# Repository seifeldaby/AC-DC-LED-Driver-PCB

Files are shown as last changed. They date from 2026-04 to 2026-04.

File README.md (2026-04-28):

# ⚡ AC-to-DC LED Driver PCB — Five-Channel Infrared LED Driver NOTE : photos under review

<p align="center">
  Final Board Powered On
</p>

<p align="center">
  
  
  
  
</p>

---

## 📋 Project Overview

This project is a **fully hand-fabricated AC-to-DC regulated power supply** designed to drive **five infrared LEDs** simultaneously. It was developed as part of the Electrical & Electronics Engineering curriculum at **Assiut University**, under the supervision of **Dr. Khalil Ismail**.

The circuit converts a **17 V peak / 50 Hz sinusoidal AC** input into a stable **9.1 V regulated DC output** using a Zener shunt regulator, and distributes ~18.8 mA to each of the five IR LED branches.

---

## 🧩 Circuit Architecture

The circuit is structured as a cascade of four functional stages:

```
AC Input → Full-Wave Bridge Rectifier → Capacitive Filter → Zener Regulator → 5× LED Branches
```

| Stage | Component | Value / Part |
|---|---|---|
| AC Input | Terminal Block (TB1) | 2-Pin, 5.08 mm pitch |
| Rectifier | D1–D4 | 1N4007 (×4) |
| Filter | C1 | 2200 µF / 50 V Electrolytic |
| Pre-reg Resistor | R1 | 47 Ω, ≥ 1 W |
| Zener Regulator | D5 | 1N4739A (9.1 V, 1 W) |
| LED Resistors | R2–R6 | 420 Ω, ¼ W (×5) |
| LEDs | LED1–LED5 | Infrared LEDs (Vf ≈ 1.2 V) |

---

## 📐 Key Design Calculations

| Parameter | Value |
|---|---|
| AC Peak Voltage | 17 V |
| AC RMS Voltage | 12.02 V |
| Peak Voltage After Rectifier | 15.6 V |
| Ripple Voltage (p-p) | ~0.2 V |
| Regulated Output (Zener) | 9.1 V |
| Current Through R1 | ~134 mA |
| Zener Current (max) | ~90 mA |
| Zener Power Dissipation (max) | ~0.82 W |
| Current Per LED Branch | ~18.8 mA |
| Total LED Current | ~94 mA |

---

## 🖥️ Step 1 — Schematic Design in LTspice

The circuit was first drawn and simulated in **LTspice** using a `.tran 0.5` transient analysis (500 ms window) to verify rectification, filtering, and regulation behaviour before committing to PCB layout.

<p align="center">
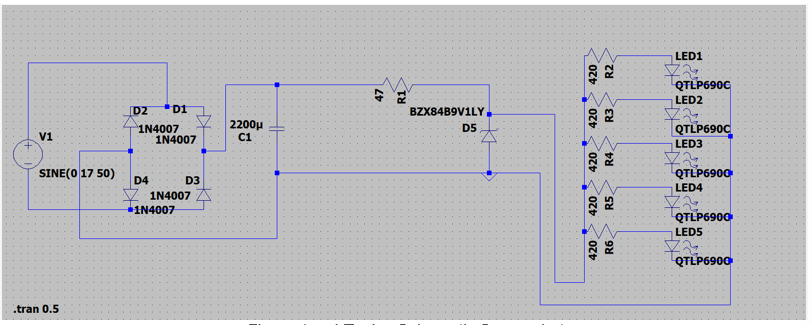
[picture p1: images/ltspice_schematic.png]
LTspice Schematic
  
  <br><em>Figure 1 — LTspice Schematic</em>
</p>

### Simulation Waveforms

**Rectified & Filtered DC Voltage (V_cap):**

<p align="center">
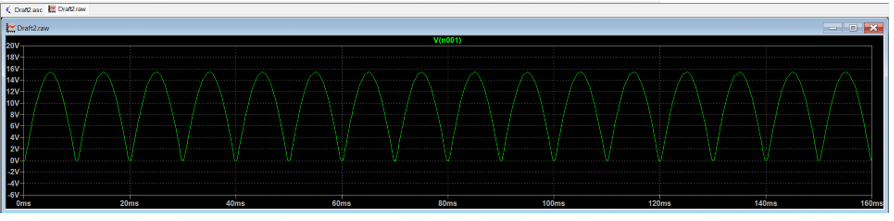
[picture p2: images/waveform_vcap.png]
Rectified and Filtered DC
  
  <br><em>Figure 2 — V_cap: Pulsating DC before regulation (~15.4 V with 0.2 V ripple)</em>
</p>

**Regulated Zener Output (9.1 V):**

<p align="center">
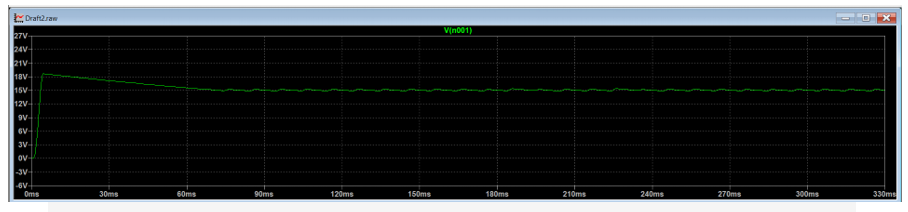
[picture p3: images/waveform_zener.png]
Zener Regulated Output
  
  <br><em>Figure 3 — Stable 9.1 V regulated output</em>
</p>

---

## 🖨️ Step 2 — PCB Design in KiCad

After successful simulation, the schematic was transferred to **KiCad** for PCB layout. Key design decisions included:

- AC input traces routed with **≥ 2 mm creepage/clearance** from DC traces (per IEC 60950)
- Zener diode and R1 placed close together to **minimise high-current trace length**
- LED resistors (R2–R6) arranged in a **symmetrical column** matching LED positions
- Terminal block mounted at **board edge** for direct cable access
- All components on the **top layer**; solder joints on the **bottom layer**

<p align="center">
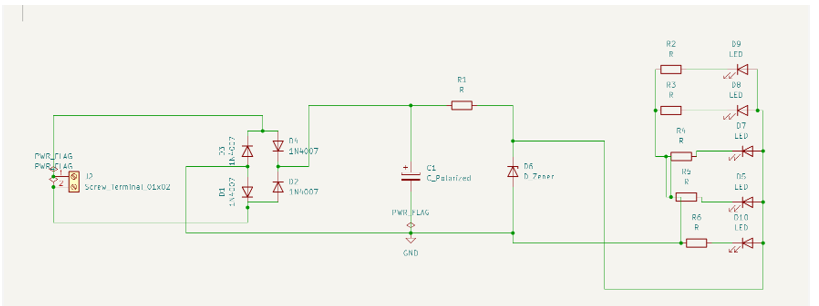
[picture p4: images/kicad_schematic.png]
KiCad Schematic
  
  <br><em>Figure 5 — Schematic captured in KiCad</em>
</p>

<p align="center">
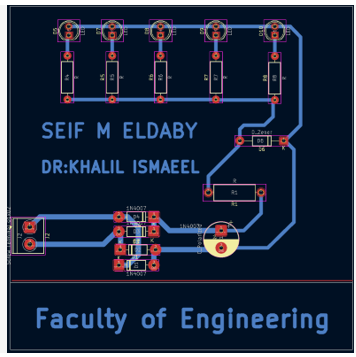
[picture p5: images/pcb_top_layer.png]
PCB Top Layer
  
  <br><em>Figure 6 — PCB Top Layer Layout</em>
</p>

<p align="center">
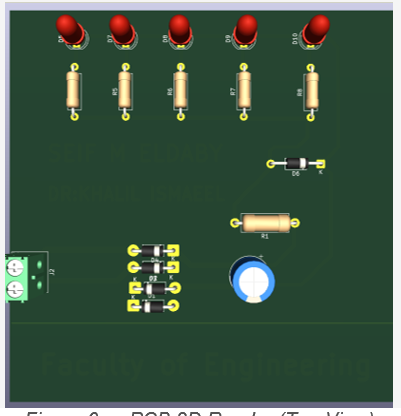
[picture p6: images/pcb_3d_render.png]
PCB 3D Render
  
  <br><em>Figure 7 — PCB 3D Render (Top View)</em>
</p>

---

## 🏭 Step 3 — PCB Manual Fabrication

The board was fabricated entirely by hand using the **toner transfer method**. Below is the complete process:

### 3.1 Toner Transfer

The layout was printed on **glossy paper** using a laser printer, then heat-transferred onto the copper-clad board using an iron.

<p align="center">
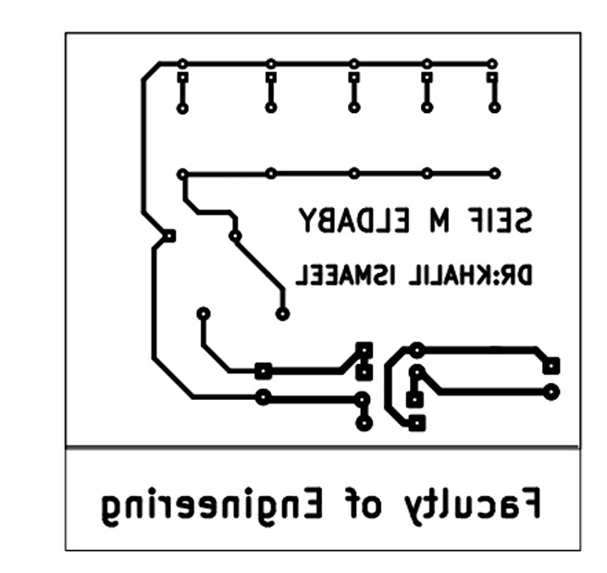
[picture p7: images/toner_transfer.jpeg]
Toner Transfer
  
  <br><em>Figure 8 — Toner transferred onto copper-clad board</em>
</p>

### 3.2 Chemical Etching

The board was submerged in **Ferric Chloride (FeCl₃)** solution to dissolve the exposed copper, leaving only the toner-protected traces.

<p align="center">
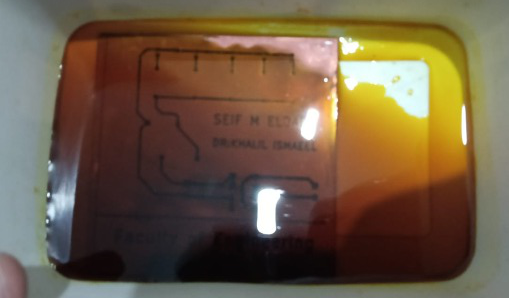
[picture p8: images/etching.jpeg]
Chemical Etching
  
  <br><em>Figure 9 — Board during chemical etching process</em>
</p>
<p align="center">
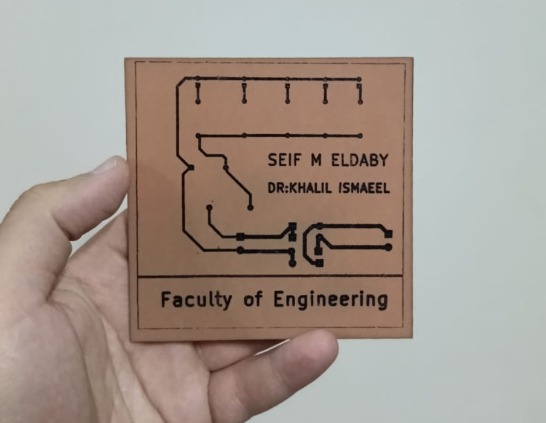
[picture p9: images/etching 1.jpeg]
Chemical Etching
  
</p>
### 3.3 Cleaning & Inspection

Toner was removed with **Acetone/Thinner** to reveal the copper tracks. A visual inspection was performed to check for shorts or broken traces.

<p align="center">
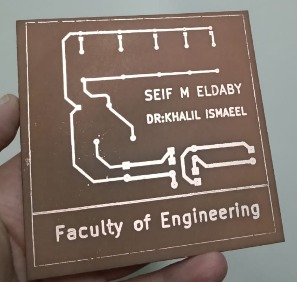
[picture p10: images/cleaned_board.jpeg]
Cleaned Board
  
  <br><em>Figure 10 — Board after cleaning, copper traces visible</em>
</p>

### 3.4 Continuity Testing

A **Digital Multimeter** was used to verify electrical integrity of all traces before drilling.

<p align="center">
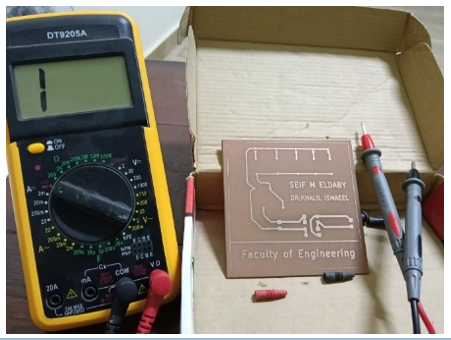
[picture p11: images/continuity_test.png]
Continuity Testing
  
  <br><em>Figure 11 — Continuity testing with DMM</em>
</p>

### 3.5 Drilling

Precision holes were drilled using a **mini drill press** with bit sizes of **0.8 mm – 1.0 mm** depending on component lead diameter.

<p align="center">
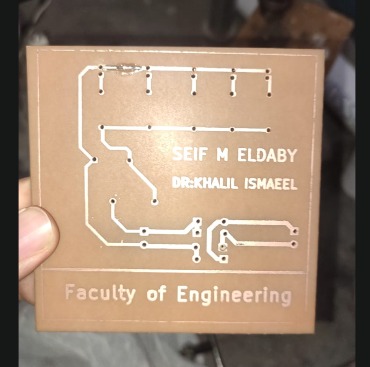
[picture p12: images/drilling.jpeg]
Drilling
  
  <br><em>Figure 12 — Drilling through-hole component pads</em>
</p>

### 3.6 Component Assembly & Soldering

Components were placed per the silkscreen layout and soldered using a **temperature-controlled iron** with lead-tin wire, targeting concave solder joints for maximum reliability.
</p>
<p align="center">
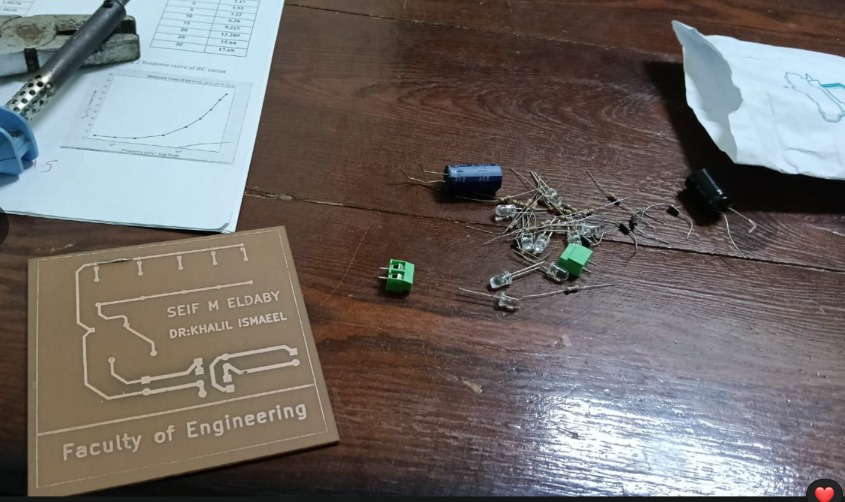
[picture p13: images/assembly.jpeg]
  
  <br><em>Figure 13 — Components being assempled onto the board</em>
</p>
<p align="center">
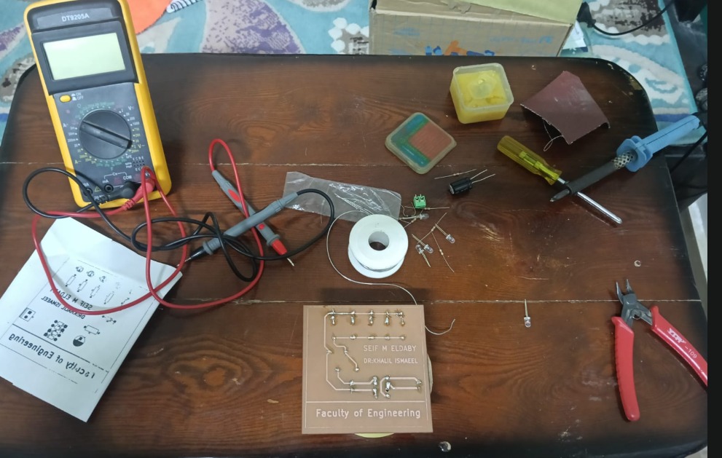
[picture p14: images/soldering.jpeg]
Soldering
  
  <br><em>Figure 13 — Components being soldered onto the board</em>
</p>
<p align="center">
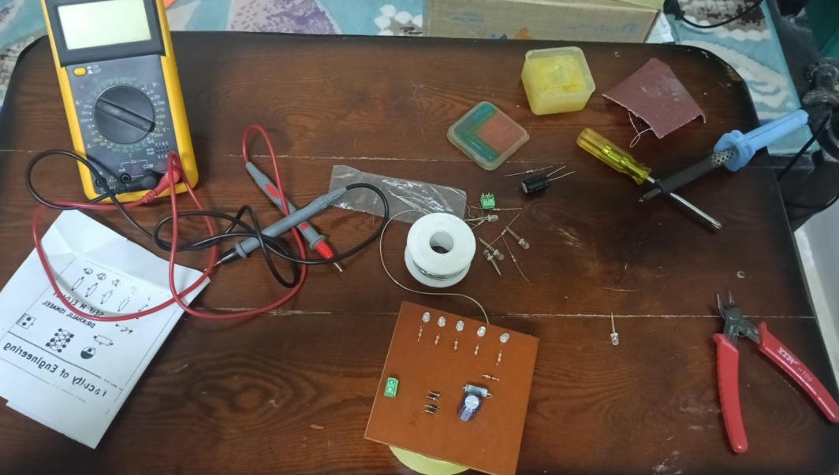
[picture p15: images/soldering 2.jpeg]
Soldering
  
  <br><em>Figure 13 — Components being soldered onto the board</em>

---

## ✅ Step 4 — Testing & Verification

After assembly, the circuit was powered through a **safety isolation transformer** for the initial power-up. Output voltage and LED branch currents were measured with a multimeter to confirm they met specifications.

<p align="center">
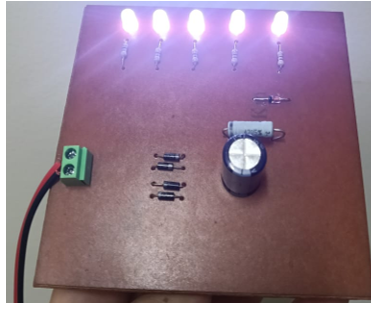
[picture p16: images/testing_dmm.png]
Testing with DMM
  
  <br><em>Figure 14 — Measuring output voltage and current </em>
</p>

---

## 🎉 Final Result

The completed board with all five IR LEDs operational:

<p align="center">
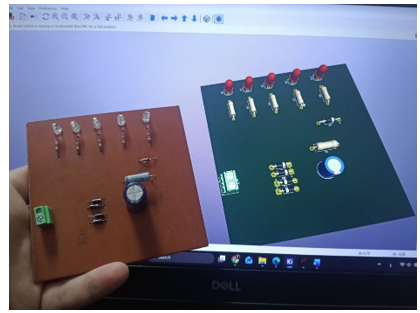
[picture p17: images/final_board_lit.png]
Final Board Powered
  
  <br><em>Figure 15 — Final assembled board with LEDs powered on</em>
</p>

The board was then cleaned with **Isopropyl Alcohol (IPA)** to remove flux residues.

---

## 🔬 Results Summary

| Measurement | Expected | Result |
|---|---|---|
| Regulated Output Voltage | 9.1 V | ✅ 9.1 V |
| LED Branch Current | ~18.8 mA | ✅ Within spec |
| Ripple Voltage | ~0.2 V p-p | ✅ Well-smoothed |
| Zener Power Dissipation | ≤ 1 W | ✅ ~0.82 W max |
| All LEDs Operational | 5/5 | ✅ 5/5 |

---

## 🛠️ Tools Used

| Tool | Purpose |
|---|---|
| **LTspice** | Circuit simulation & waveform analysis |
| **KiCad** | Schematic capture & PCB layout |
| **Ferric Chloride** | Chemical etching |
| **Soldering Iron** | Component assembly |
| **Digital Multimeter** | Continuity testing & measurements |

---

## 📁 Repository Structure

```
📦 AC-DC-LED-Driver-PCB
 ┣ 📂 images/                  ← All photos and screenshots
 ┣ 📂 ltspice/                 ← LTspice simulation files 
 ┣ 📂 kicad/                   ← KiCad project files 
 ┣ 📄 README.md                ← This file
 ┗ 📄 LED_Driver_PCB_Report.pdf ← Full technical report
```

---

## 👤 Author

**Seif Elden Mostafa Salah Eldaby**  
Electrical & Electronics Engineering — Assiut University (Class of 2029)  

**Supervisor:** Dr. Khalil Ismail  
Faculty of Engineering — Assiut University

---

## 📄 License

This project is submitted as academic work at Assiut University. Feel free to use it for learning purposes with proper attribution.

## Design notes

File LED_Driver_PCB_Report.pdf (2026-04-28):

AC-to-DC LED Driver Circuit — Technical Report

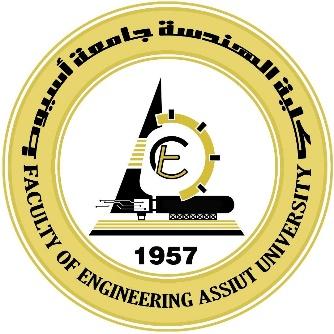
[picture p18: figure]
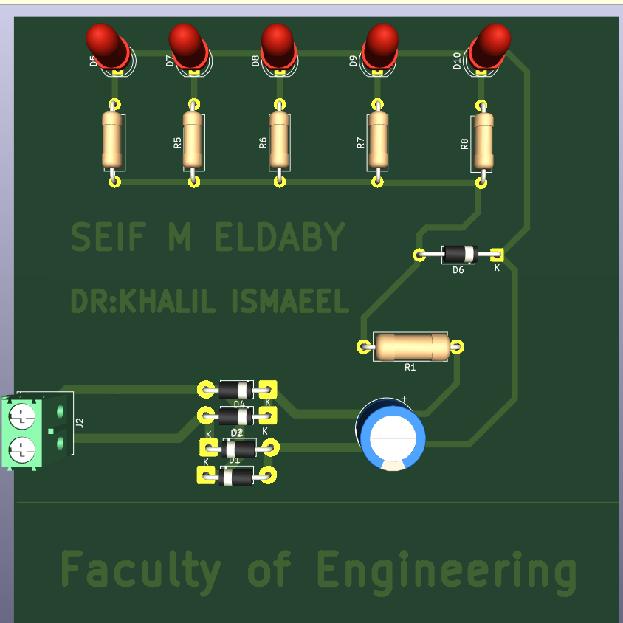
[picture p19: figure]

Assiut University — EEE Department | Page 1

## ASSIUT UNIVERSITY

Faculty of Engineering — Electrical & Electronics Engineering Department

### TECHNICAL REPORT

## AC-to-DC Power Supply with Zener Regulation

### for a Five-Channel Infrared LED Driver

## Prepared by :Seif Elden Mostafa Salah

# Supervisor: Dr. Khalil Ismail

## 1. Introduction

This report documents the design, analysis, and PCB implementation of an AC-to-DC regulated power supply circuit intended to drive five infrared LEDs . The circuit converts a 50 Hz sinusoidal AC input into a stable regulated DC voltage using a full-wave bridge rectifier, a bulk filter capacitor, a dropping resistor, and a 9.1 V Zener diode regulator. The regulated output is distributed to five identical LED branches, each protected by a dedicated current-limiting resistor.
The project was simulated in LTspice and then implemented as a printed circuit board (PCB). The actual hardware substitutes the schematic's terminal connections with a dedicated 2-pin terminal block (5.08 mm pitch) and uses a 1N4739A (9.1 V, 1 W) Zener diode in place of the BZX84B9V1LY used in simulation.

## 2. Circuit Description and Block Diagram

### 2.1 Functional Blocks

The circuit consists of four main stages connected in cascade:
- AC Input Stage — A terminal block accepts the mains-derived sinusoidal input (17 V peak, 50 Hz).
- Full-Wave Bridge Rectifier — Four 1N4007 diodes (D1–D4) form a bridge that rectifies both half-cycles of the AC waveform into a pulsating DC.
- Capacitive Filter — A 2200 µF electrolytic capacitor (C1) smooths the pulsating DC, greatly reducing ripple voltage.
- Zener Shunt Regulator — A 47 Ω series resistor (R1) and a 9.1 V Zener diode (D5, 1N4739A) clamp the output to a stable 9.1 V regardless of moderate load and input variations.
- LED Load Stage — Five parallel branches, each consisting of a 420 Ω resistor in series with LED.

### 2.2 Component List

Ref. | Description | Value / Part Number | Qty
V1 | AC Voltage Source | SINE(0, 17V, 50Hz) | 1
D1–D4 | Rectifier Diodes | 1N4007 | 4
C1 | Filter Capacitor | 2200 µF / 50 V Electrolytic | 1
R1 | Current Limiting / Pre-reg Resistor | 47 Ω | 1
D5 | Zener Voltage Regulator | 1N4739A (9.1 V, 1 W) | 1
R2–R6 | LED Current Limiting Resistors | 420 Ω | 5
LED1– LED5 | Infrared LEDs | White (3.7 v) | 5
TB1 | Terminal Block | 2-Pin, 5.08 mm Pitch | 1

## 3. Design Calculations

### 3.1 Peak and RMS Input Voltage

The AC source is defined in simulation as SINE(0, 17, 50), meaning:
- Peak voltage: Vpeak = 17 V
- RMS voltage: V_rms = Vpeak / √2 = 17 / 1.4142 ≈ 12.02 V
- Frequency: f = 50 Hz → Period T = 20 ms

### 3.2 Rectifier Output (Before Filter)

The bridge rectifier drops two diode forward voltages in series during each conduction interval. Using V_f = 0.7 V for 1N4007:
- DC average after rectifier (no filter): V_dc = (2 × Vpeak / π) − 2 × V_f
- V_dc = (2 × 17 / 3.1416) − 1.4 = 10.82 − 1.4 ≈ 9.42 V (unloaded average)
- Peak after rectifier: V_peak_rect = 17 − 1.4 = 15.6 V

### 3.3 Filter Capacitor Ripple

With C1 = 2200 µF and the rectifier operating at full-wave frequency (2f = 100 Hz):
- Ripple voltage (approximate): V_ripple = I_load / (2 × f × C)
- Estimated total load current (see §3.5): I_load ≈ 44 mA
- V_ripple = 0.044 / (2 × 50 × 0.0022) = 0.044 / 0.22 ≈ 0.2 V (peak-to-peak)
- This gives a well-smoothed DC of approximately 15.4 V ± 0.1 V at the capacitor.

### 3.4 Zener Regulator Stage

The regulated output voltage is set by the Zener diode:
- Zener voltage: V_Z = 9.1 V (1N4739A, 1 W power rating)
- Series resistor: R1 = 47 Ω
- Voltage across R1: V_R1 = V_cap − V_Z = 15.4 − 9.1 = 6.3 V
- Total current through R1: I_R1 = V_R1 / R1 = 6.3 / 47 ≈ 134 mA
- LED branch current (see §3.5): I_LEDs_total ≈ 44 mA
- Zener current: I_Z = I_R1 − I_LEDs_total = 134 − 44 = 90 mA
- Zener power dissipation: P_Z = V_Z × I_Z = 9.1 × 0.090 ≈ 0.82 W (within 1 W rating)
- R1 power dissipation: P_R1 = I_R1² × R1 = (0.134)² × 47 ≈ 0.84 W (use ≥ 1 W resistor)

### 3.5 LED Branch Calculations

Each LED branch consists of a 420 Ω resistor in series with a QTLP690C infrared LED. Assuming a typical LED forward voltage V_f_LED = 1.2 V:
- Voltage across each resistor: V_Rn = V_Z − V_f_LED = 9.1 − 1.2 = 7.9 V
- Current per LED branch: I_LED = V_Rn / R_n = 7.9 / 420 ≈ 18.8 mA
- Total LED current (5 branches): I_total = 5 × 18.8 = 94 mA
- Power dissipated per resistor: P_Rn = I_LED² × 420 = (0.0188)² × 420 ≈ 0.148 W (use ¼ W)
- Power dissipated per LED: P_LED = V_f_LED × I_LED = 1.2 × 0.0188 ≈ 22.6 mW

Note: Recalculating the Zener current with updated load: I_Z = 134 − 94 = 40 mA → P_Z = 9.1 × 0.040 ≈ 0.36 W. Both scenarios remain within the 1 W Zener rating.

### 3.6 Summary Table of Key Design Values

Parameter | Calculated Value | Unit
AC Peak Voltage | 17 | V
AC RMS Voltage | 12.02 | V
Peak Voltage After Rectifier | 15.6 | V
Ripple Voltage (p-p) | ~0.2 | V
Regulated Output Voltage (Zener) | 9.1 | V
Current Through R1 | ~134 | mA
Zener Current (max case) | ~90 | mA
Zener Power Dissipation (max) | ~0.82 | W
Current Per LED Branch | ~18.8 | mA
Total LED Current | ~94 | mA
Power Per LED Resistor | ~0.148 | W

## 4. Component Selection and Justification

### 4.1 Rectifier Diodes — 1N4007

The 1N4007 is a general-purpose rectifier diode with a peak inverse voltage (PIV) of 1000 V and average forward current rating of 1 A. The peak inverse voltage seen by each diode in the bridge is equal to the peak supply voltage (17 V), well within the 1000 V rating. The forward current through each diode equals the total load current during conduction, approximately 134 mA, also safely within the 1 A rating.

### 4.2 Filter Capacitor — 2200 µF

A 2200 µF / 50 V electrolytic capacitor provides sufficient bulk capacitance to reduce the 100 Hz ripple to less than 0.2 V under the expected load. The 50 V voltage rating provides more than three times the expected peak voltage (15.6 V), ensuring long-term reliability. Larger capacitance could reduce ripple further but would increase inrush current and PCB footprint.

### 4.3 Zener Diode — 1N4739A (9.1 V, 1 W)

The 1N4739A is a through-hole 1 W Zener diode in a DO-41 package with a regulation voltage of 9.1 V. It replaces the SMD BZX84B9V1LY used in simulation, offering the same regulation point with higher power dissipation capability (1 W vs. 300 mW). This is important because the Zener may need to sink up to ~90 mA under light load, dissipating up to 0.82 W, which exceeds the capability of the 300 mW SMD variant.

### 4.4 LED Current-Limiting Resistors — 420 Ω

A resistance of 420 Ω limits the LED branch current to approximately 18.8 mA, within the absolute maximum forward current of 30 mA. This provides adequate IR radiant intensity while keeping power dissipation per resistor below 0.15 W, suitable for standard 1/4 W carbon film resistors.

### 4.5 Terminal Block — 2-Pin, 5.08 mm Pitch

The 5.08 mm pitch terminal block provides a robust, tool-accessible screw connection for the AC input wires. It replaces any loose wire connections in the prototype and is rated for currents well above the circuit's demand, improving safety and reliability in the final PCB assembly.

## 5. Methodology

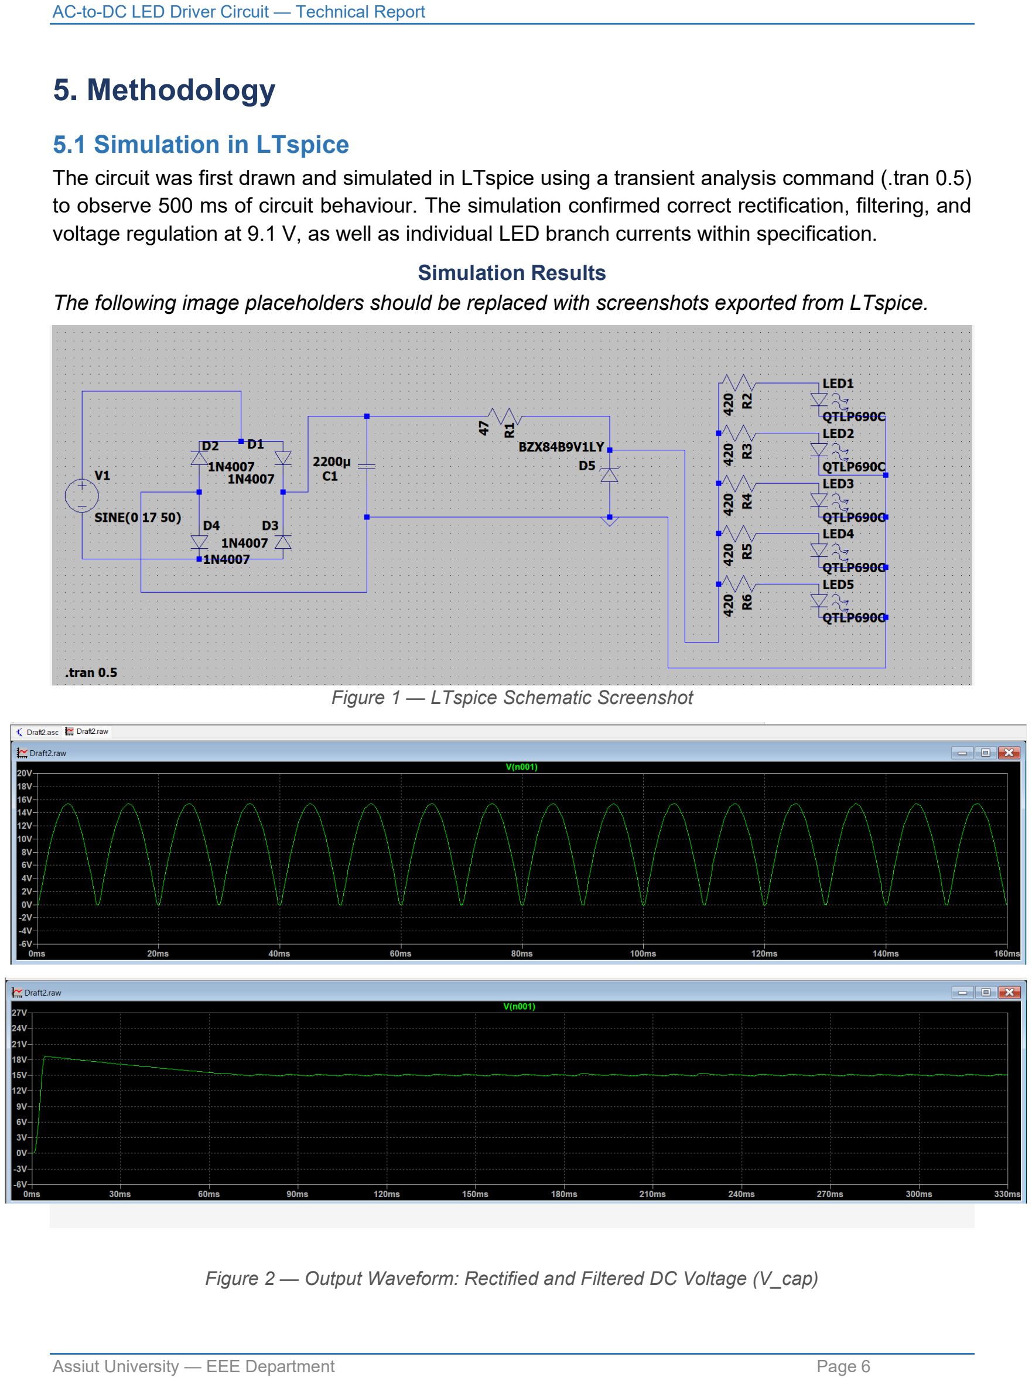
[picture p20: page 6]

### 5.1 Simulation in LTspice

The circuit was first drawn and simulated in LTspice using a transient analysis command (.tran 0.5) to observe 500 ms of circuit behaviour. The simulation confirmed correct rectification, filtering, and voltage regulation at 9.1 V, as well as individual LED branch currents within specification.

Simulation Results
The following image placeholders should be replaced with screenshots exported from LTspice.

Figure 1 — LTspice Schematic Screenshot

Figure 2 — Output Waveform: Rectified and Filtered DC Voltage (V_cap)

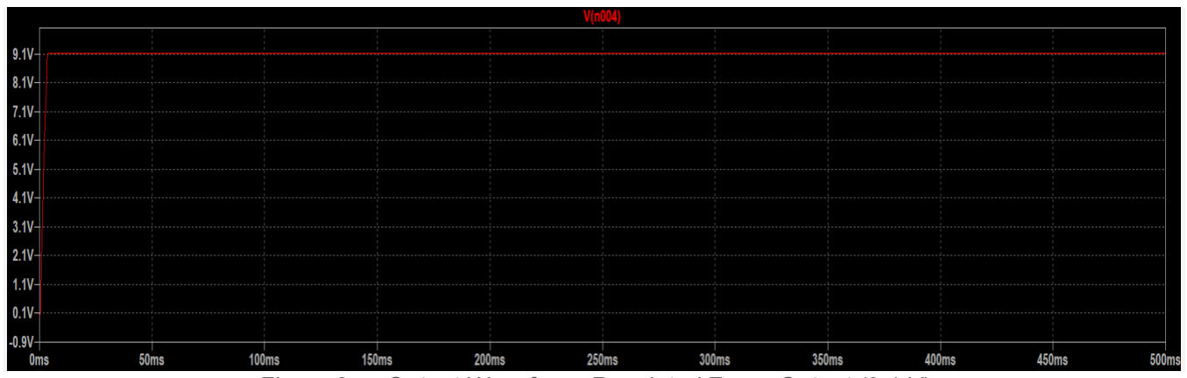
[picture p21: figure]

Figure 3 — Output Waveform: Regulated Zener Output (9.1 V)

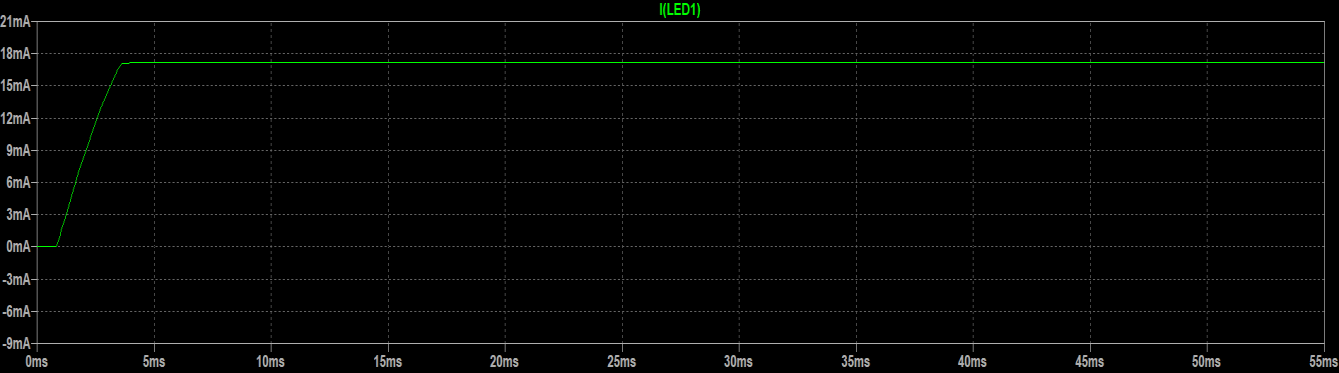
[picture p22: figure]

Figure 4 — LED Branch Currents (I_LED1 through I_LED5)

### 5.2 PCB Design

Following successful simulation, the schematic was transferred to a PCB layout tool. The following design decisions were applied:
- AC input traces routed with adequate creepage and clearance distance from DC traces (minimum 2 mm for 50 V working voltage, per IEC 60950).
- The Zener diode and series resistor R1 placed close together to minimise high-current trace length.
- LED driver resistors (R2–R6) arranged in a column mirroring the LED positions for a clean, symmetrical layout.
- 2-pin terminal block mounted at the board edge for direct cable access.
- All through-hole components on the top layer; solder joints on the bottom layer.

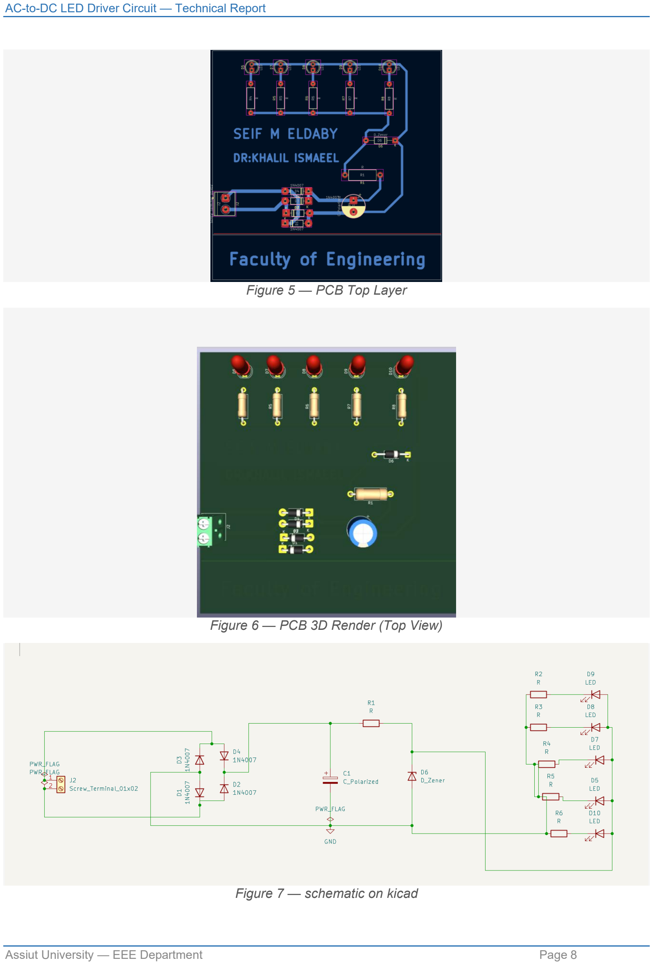
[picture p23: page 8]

Figure 5 — PCB Top Layer

Figure 6 — PCB 3D Render (Top View)

Figure 7 — schematic on kicad

## 6. Results and Discussion

The simulation results confirmed that the full-wave bridge rectifier produces a pulsating DC with a peak of 15.6 V. After filtering with the 2200 µF capacitor, the ripple was reduced to approximately 0.2 V peak-to-peak, yielding a stable pre-regulation supply of ~15.4 V.
The Zener shunt regulator successfully clamped the output at 9.1 V. The series resistor R1 = 47 Ω carried approximately 134 mA, shared between the Zener diode and the LED load. Each of the five LED branches drew approximately 18.8 mA, producing sufficient infrared radiance from the QTLP690C LEDs while remaining well below the absolute maximum forward current.
The substitution of the SMD Zener (BZX84B9V1LY) with the 1 W through-hole 1N4739A in the PCB implementation ensures adequate thermal margin. Power dissipation calculations confirmed that the Zener operates within its 1 W rated maximum under all expected load conditions.

## 7. Conclusion

A compact AC-to-DC regulated LED driver circuit has been successfully designed, simulated, and implemented on a printed circuit board. The design achieves a stable 9.1 V regulated output from a 12 V RMS / 17 V peak AC source and distributes approximately 18.8 mA to each of LEDs. All components were selected with adequate voltage, current, and power margins. The PCB layout adheres to good engineering practices regarding trace routing, component placement, and creepage/clearance requirements.

Manufacturing Process Steps

In this section, the manual fabrication process of the PCB is detailed through the following stages:

- 1. Toner Transfer: The circuit layout was printed using a laser printer on glossy paper and then transferred onto the copper-clad board using heat (ironing method).
- 2. Chemical Etching: The board was immersed in an etching solution (Ferric Chloride) to remove the unwanted copper, leaving only the protected traces.
- 3. Cleaning and Inspection: After etching, the toner was removed using a solvent (like Thinner or Acetone) to reveal the clean copper tracks. A visual inspection was performed to ensure no shorts or breaks.
- 4. Continuity Testing: Using a Digital Multimeter, a continuity test was conducted to verify the electrical integrity of all traces before proceeding to the drilling and soldering phases.
- 5. Component Preparation: The electronic components (LEDs, capacitors, and terminal blocks) were prepared and organized for the final assembly.
- 6. Drilling: Precision holes were drilled for the through-hole components (THD) using a mini-drill press. Drill bit sizes were selected based on component lead diameters (typically 0.8mm to 1mm).
- 7. Component Assembly & Soldering: Components were placed according to the silk-screen layout. Soldering was performed using a temperature-controlled soldering iron and high-quality lead-tin wire, ensuring "concave" solder joints for maximum mechanical and electrical reliability.
- 8. Final Testing & Calibration: After assembly, the circuit was connected to the AC source through a safety isolation transformer (or series lamp) for initial power-up. Output voltage and current were measured using the multimeter to ensure they met the LED driver specifications.
- 9. Enclosure & Final Inspection: A final visual check was done to ensure no cold solder joints or bridge shorts existed. The board was then cleaned with Iso-Propyl Alcohol (IPA) to remove flux residues, giving it a professional finish.

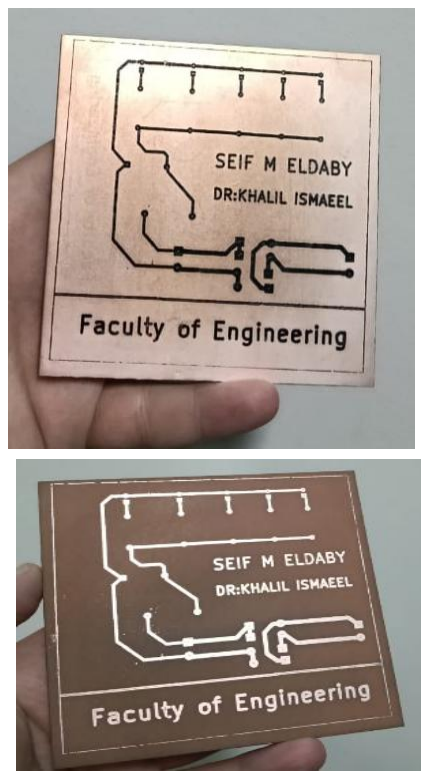
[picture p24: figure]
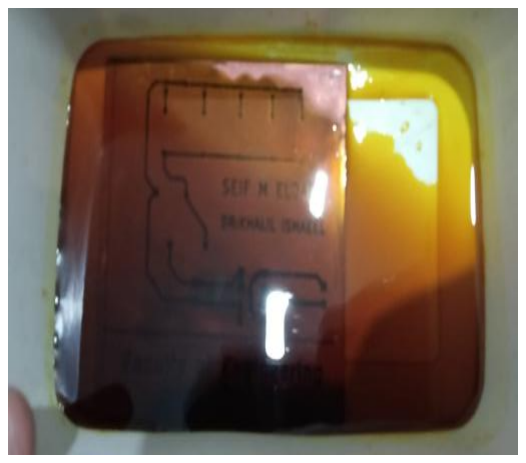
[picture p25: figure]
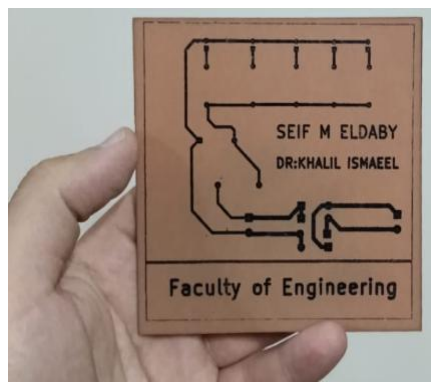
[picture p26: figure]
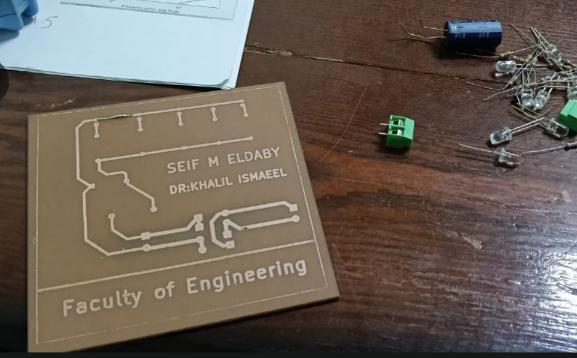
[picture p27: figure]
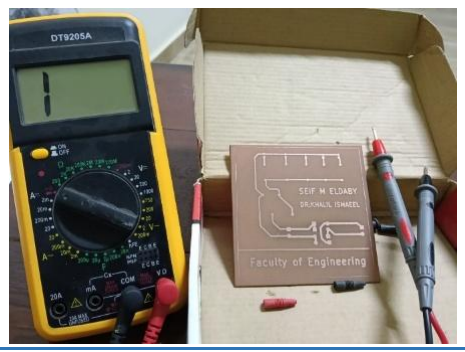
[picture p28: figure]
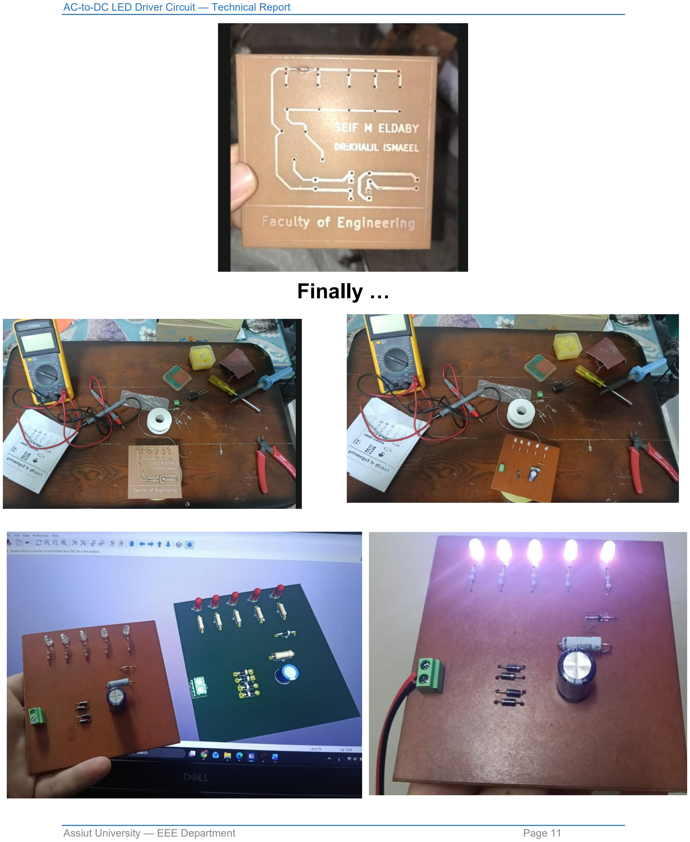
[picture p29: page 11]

## Finally …

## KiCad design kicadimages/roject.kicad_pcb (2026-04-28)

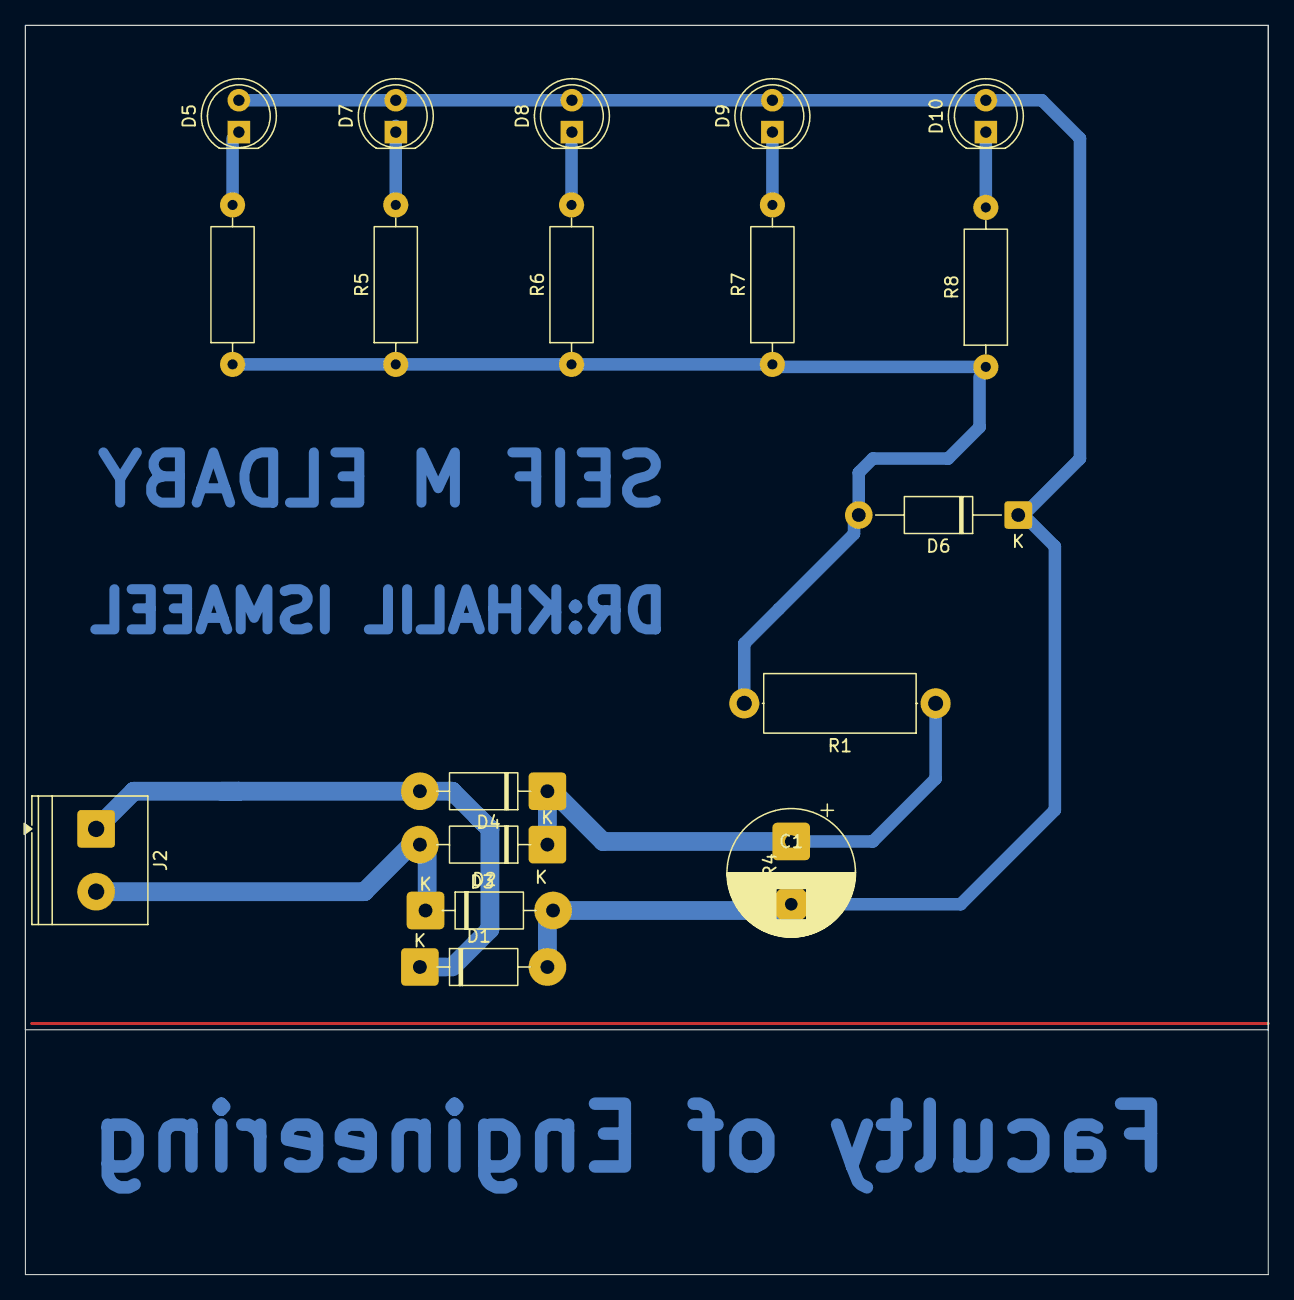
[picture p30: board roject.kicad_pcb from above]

Board: 2 copper layers, 99.0 x 99.5 mm, 18 parts (0 on the bottom side), 8 nets.

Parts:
C1: C_Polarized; CP_Radial_D10.0mm_P5.00mm
D1, D2, D3, D4: 1N4007; D_DO-41_SOD81_P10.16mm_Horizontal
D5, D7, D8, D9, D10: LED; LED_D5.0mm
D6: D_Zener; D_DO-41_SOD81_P12.70mm_Horizontal
J2: Screw_Terminal_01x02; TerminalBlock_Phoenix_PT-1,5-2-5.0-H_1x02_P5.00mm_Horizontal
R1: R; R_Axial_DIN0414_L11.9mm_D4.5mm_P15.24mm_Horizontal
R4, R5, R6, R7, R8: R; R_Axial_DIN0309_L9.0mm_D3.2mm_P12.70mm_Horizontal

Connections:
GND: C1.2, D1.2 (A), D3.2 (A), D6.2 (A), R4.1, R5.1, R6.1
unnamed: D1.1 (K), D2.2 (A)
unnamed: C1.1, D2.1 (K), D4.1 (K), R1.1, R7.1, R8.1
unnamed: D3.1 (K), D4.2 (A), J2.1
unnamed: D5.1 (K), R5.2
unnamed: D7.1 (K), R4.2
unnamed: D5.2 (A), D6.1 (K), D7.2 (A), D8.2 (A), D9.2 (A), D10.2 (A), J2.2, R1.2, R7.2, R8.2
unnamed: D10.1 (K), R6.2
